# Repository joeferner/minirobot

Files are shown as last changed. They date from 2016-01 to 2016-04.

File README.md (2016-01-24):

# Minirobot

# Microcontroller Pin Requirements

| Name | Requirements | Pin |
| --- | --- | --- |
| Debug | UART TX/RX | UART1-PA9/PA10 |
| Wheel encoder left | EXTI | PB0 |
| Wheel encoder right | EXTI | PB1 |
| Wheel servo left | PWM | TIM3-PA6 |
| Wheel servo right | PWM | TIM3-PA7 |
| Line follow left outer  | EXTI | PB12 |
| Line follow right outer | EXTI | PB14 |
| Line follow left inner  | EXTI | PB13 |
| Line follow right inner | EXTI | PB15 |
| I<sup>2</sup>C1 | SCL/SDA | PB8/PB9 |
| Compass (ST-LIS3MDL) | I<sup>2</sup>C (0x1E) | I<sup>2</sup>C1 |
| Color Sensor (TCS3472)  | I<sup>2</sup>C (0x29) | I<sup>2</sup>C1 |
| Color Sensor Interrupt  | GPIO IN | PB6 |
| Color LED | PWM | TIM4-PB7 |
| Bluetooth (RN4020) | USART TX/RX/CTS/RTS | UART2-PA2/PA3/PA0/PA1 |
| Bluetooth MLDP | GPIO OUT | PC1 |
| Bluetooth WakeSW | GPIO OUT | PC2 |
| Bluetooth WakeHW | GPIO OUT | PC3 |
| Bluetooth WS | GPIO IN | PA4 |
| Bluetooth Connection | GPIO IN | PA5 |
| Bluetooth MLDPEV | GPIO IN | PC4 |
| Battery level | ADC | VBAT |

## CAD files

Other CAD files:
mechanical/BK-5003-ND.ipt
mechanical/LW-Q38E-Q100-3K6L-1.ipt
mechanical/QRE1113.ipt
mechanical/QRE1113GR.ipt
mechanical/SS-5GL-F.ipt
mechanical/TCS3472.ipt
mechanical/assembly-pcb.iam
mechanical/assembly.iam
mechanical/battery-aaa.ipt
mechanical/bottom-test.ipt
mechanical/micro-servo.ipt
mechanical/pcb.ipt
mechanical/wheel.ipt

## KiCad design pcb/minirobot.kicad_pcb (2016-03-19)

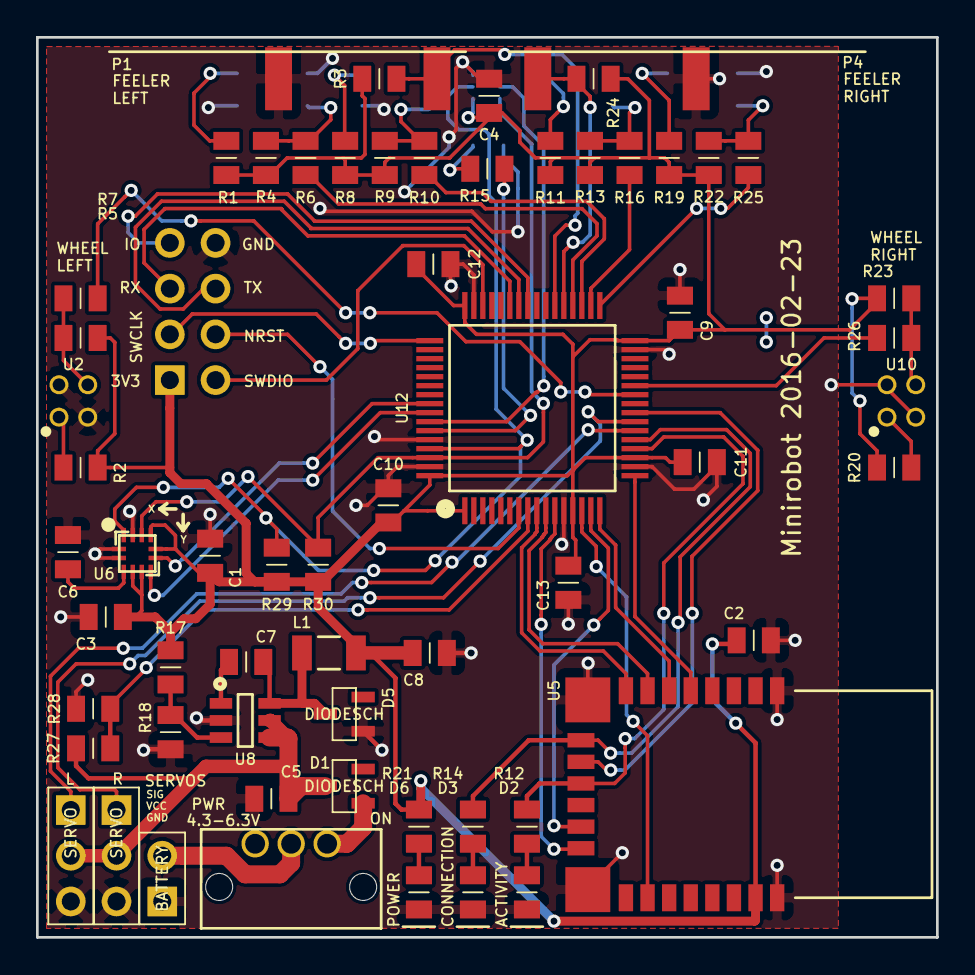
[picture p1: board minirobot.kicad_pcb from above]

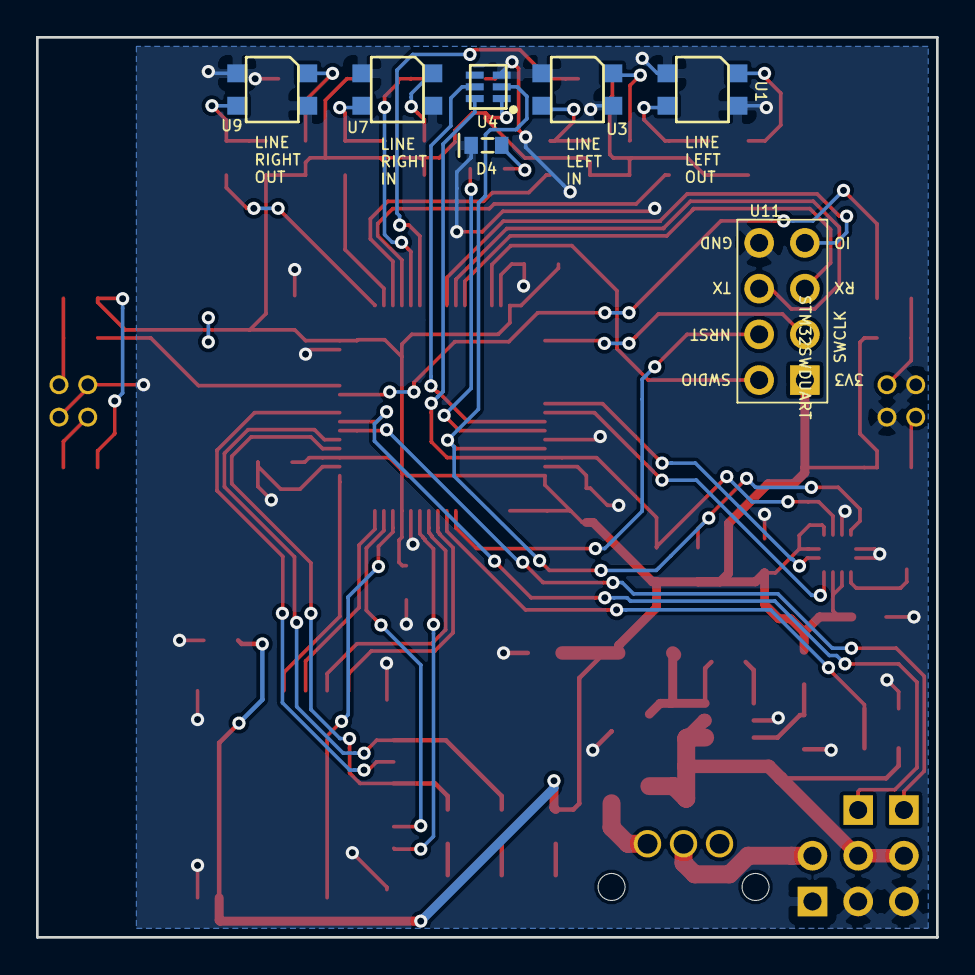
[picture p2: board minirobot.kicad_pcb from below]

Board: 2 copper layers, 50.0 x 50.0 mm, 68 parts (7 on the bottom side), 58 nets.

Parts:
C1, C4, C6, C9, C10, C11, C12, C13: 0.1uF; CAPC2012X100N
C2, C8: 10uF; CAPC2012X100N
C3: 1uF; CAPC2012X100N
C5: 10uF >6V; CAPC2012X100N
C7: 0.012uF; CAPC2012X100N
D1, D5: DIODESCH; SOT95P237X112_132-3N
D2: ACTIVITY-BLUE; LEDC2012X100N
D3: CONN-GREEN; LEDC2012X100N
D4: LED; LEDC1608X40N
D6: 3V3LED; LEDC2012X100N
L1: 4.7uH; INDC3218X180N
P1: FEELERLEFT; OMRON-SS-5GL-F-3-RAM
P2, P5: SERVO; HDRV3W66P254_1X3_762X249X838P
P3: BATTERY; HDRV2W66P254_1X2_508X249X838P
P4: FEELERRIGHT; OMRON-SS-5GL-F-3-RA
R1, R2, R8, R11, R15, R19, R20: 51R; RESC2012X100N
R3, R4, R5, R9, R13, R22, R23, R24, R27, R28: 10K; RESC2012X100N
R6, R7, R10, R16, R25, R26: 0R; RESC2012X100N
R12, R14, R21: 100R; RESC2012X100N
R17: 62K; RESC2012X100N
R18: 20K; RESC2012X100N
R29, R30: 4.7K; RESC2012X100N
S1: POWER; COPAL-MFS101D-6-Z
U1: LINELEFTOUT; QRE1113GR
U2: WHEELLEFT; QRE1113-RA
U3: LINELEFTIN; QRE1113GR
U4: TCS3472
U5: RN4020
U6: ST-LIS3MDL; LGA12S50P4X4_192X192X100
U7: LINERIGHTIN; QRE1113GR
U8: DIODES-AP3211; SOT95P270X145-6N
U9: LINERIGHTOUT; QRE1113GR
U10: WHEELRIGHT; QRE1113-RA
U11: STM32SWDUART; HDRV8W64P254_2X4_1016X483X838P
U12: STM32F411RET6; QFP50P1200X1200X160-64N

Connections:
+3.3V: C1.1, C2.1, C3.1, C4.1, C8.1, C9.1, C10.1, C11.1, C12.1, C13.1, L1.1, R1.1, R2.1, R3.2, R4.2, R5.2, R8.1, R9.2, R11.1, R13.2, R17.1, R19.1, R20.1, R21.1, R22.2, R23.2, R24.2, R29.1, R30.1, U4.1, U5.23, U6.5, U6.6, U6.9, U6.10, U11.1, U12.1, U12.13, U12.19, U12.32, U12.48, U12.64
/Bluetooth/BLECONN: R14.1, U5.10, U12.21
/Bluetooth/BLEMLDP: U5.8, U12.9
/Bluetooth/BLEMLDPEV: U5.11, U12.24
/Bluetooth/BLEUARTCTS: U5.14, U12.15
/Bluetooth/BLEUARTRTS: U5.18, U12.14
/Bluetooth/BLEUARTRX: U5.6, U12.16
/Bluetooth/BLEUARTTX: U5.5, U12.17
/Bluetooth/BLEWAKEHW: U5.15, U12.11
/Bluetooth/BLEWAKESW: U5.7, U12.10
/Bluetooth/BLEWS: R12.1, U5.12, U12.20
/Compass/COMPASSINT: U6.7, U12.57
/Compass/COMPASSRDY: U6.8, U12.56
/Compass/I2CSCL: R29.2, U4.2, U6.1, U12.61
/Compass/I2CSDA: R30.2, U4.6, U6.11, U12.62
/DEBUGGPIO: U11.7, U12.41
/DEBUGRX: U11.5, U12.43
/DEBUGTX: U11.6, U12.42
/NRST: U11.4, U12.7
/SWCLK: U11.3, U12.49
/SWDIO: U11.2, U12.46
/Sensors/COLORINT: U4.5, U12.58
/Sensors/COLORLED: R15.2, U12.59
/Sensors/FEELERLEFT: P1.1, R3.1, U12.38
/Sensors/FEELERRIGHT: P4.1, R24.1, U12.37
/Sensors/LINELEFTIN: R10.1, U12.35
/Sensors/LINELEFTOUT: R6.1, U12.36
/Sensors/LINERIGHTIN: R16.1, U12.34
/Sensors/LINERIGHTOUT: R25.1, U12.33
/Sensors/SERVOLEFT: P2.1, U12.22
/Sensors/SERVORIGHT: P5.1, U12.23
/Sensors/WHEELLEFT: R7.1, U12.26
/Sensors/WHEELRIGHT: R26.1, U12.27
/VBAT: R27.2, R28.1, U12.8
GNDPWR: C1.2, C2.2, C3.2, C4.2, C5.2, C6.2, C8.2, C9.2, C10.2, C11.2, C12.2, C13.2, D2.2, D3.2, D4.2, D5.1, D6.2, P1.2, P2.3, P3.1, P4.2, P5.3, R18.2, R28.2, U1.2, U1.4, U2.2, U2.4, U3.2, U3.4, U4.3, U5.1, U5.9, U5.16, U5.24, U6.2, U6.3, U6.12, U7.2, U7.4, U8.2, U9.2, U9.4, U10.2, U10.4, U11.8, U12.12, U12.18, U12.31, U12.47, U12.60, U12.63
unnamed: C6.1, U6.4
unnamed: C7.1, U8.1
unnamed: C7.2, D5.2, L1.2, U8.6
unnamed: D1.1, S1.3
unnamed: D2.1, R12.2
unnamed: D3.1, R14.2
unnamed: D4.1, R15.1
unnamed: D6.1, R21.2
unnamed: P3.2, S1.2
unnamed: R1.2, U1.1
unnamed: R2.2, U2.1
unnamed: R4.1, R6.2, U1.3
unnamed: R5.1, R7.2, U2.3
unnamed: R8.2, U3.1
unnamed: R9.1, R10.2, U3.3
unnamed: R11.2, U7.1
unnamed: R13.1, R16.2, U7.3
unnamed: R17.2, R18.1, U8.3
unnamed: R19.2, U9.1
unnamed: R20.2, U10.1
unnamed: R22.1, R25.2, U9.3
unnamed: R23.1, R26.2, U10.3
Vcc: C5.1, D1.2, P2.2, P5.2, R27.1, U8.4, U8.5

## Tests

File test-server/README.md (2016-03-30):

```
sudo modprobe btusb
sudo systemctl start bluetooth.service
sudo hciconfig hci0 up
sudo setcap cap_net_raw+eip $(eval readlink -f `which node`)
```

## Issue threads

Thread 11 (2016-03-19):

Move compass to make it easier to rework solder

joeferner, 2016-03-19:

Closed 2016-03-19.

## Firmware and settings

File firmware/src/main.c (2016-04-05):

#include "platform_config.h"
#include "compass.h"
#include "servo.h"
#include "colorSensor.h"
#include "exti.h"
#include "ble.h"
#include "battery.h"
#include <utils/debug.h>
#include <utils/time.h>
#include <utils/utils.h>
#include <string.h>

typedef enum {
  DEBUG_MODE_NOT_SET,
  DEBUG_MODE_SERVO,
  DEBUG_MODE_BLE
} _DebugMode;

void _printPrompt();

_DebugMode _debugMode;

void setup() {
  _debugMode = DEBUG_MODE_NOT_SET;
  debug_setup();
  sleep_ms(100);
  DEBUG_OUT("setup\n");

  assertNonOKHALStatus(compass_setup());
  assertNonOKHALStatus(servo_setup());
  assertNonOKHALStatus(exti_setup());
  assertNonOKHALStatus(colorSensor_setup());
  assertNonOKHALStatus(ble_setup());
  assertNonOKHALStatus(battery_setup());

  colorSensor_setGain(1);
  ble_updateColorSensorGain(1);

  colorSensor_setLedBrightness(50);
  ble_updateColorSensorLedBrightness(50);

  DEBUG_OUT("setup complete\n");
  _printPrompt();
}

void loop() {
  debug_tick();
  compass_tick();
  servo_tick();
  colorSensor_tick();
  ble_tick();
  battery_tick();
}

void onBatteryLevelUpdate(uint8_t level) {
  //DEBUG_OUT("battery level: %d\n", level);
  ble_updateBatteryLevel(level);
}

void onFeeler(Feeler feeler, bool active) {
  /*
  DEBUG_OUT(
    "feeler: %s %s\n",
    feeler == FEELER_LEFT ? "left" : "right",
    active ? "on" : "off"
  );
  */
  ble_updateFeeler(feeler, active);
}

void onWheelSensor(WheelSensor wheelSensor, bool active) {
  /*
  DEBUG_OUT(
    "wheelSensor: %s %s\n",
    wheelSensor == WHEEL_SENSOR_LEFT ? "left" : "right",
    active ? "on" : "off"
  );
  */
}

void onLineSensor(LineSensor lineSensor, bool active) {
  /*
  const char* sensorName = "";
  switch (lineSensor) {
  case LINE_SENSOR_LEFT_IN:
    sensorName = "left in";
    break;
  case LINE_SENSOR_LEFT_OUT:
    sensorName = "left out";
    break;
  case LINE_SENSOR_RIGHT_IN:
    sensorName = "right in";
    break;
  case LINE_SENSOR_RIGHT_OUT:
    sensorName = "right out";
    break;
  }
  DEBUG_OUT("lineSensor: %s %s\n", sensorName, active ? "on" : "off");
  */
  ble_updateLineSensor(lineSensor, active);
}

void onBLESetMotor(int8_t left, int8_t right) {
  DEBUG_OUT("ble set motor: %d %d\n", left, right);
  servo_setSpeed(left, right);
}

void onBLEWriteConfiguration(BLE_Configuration* configuration) {
  colorSensor_setGain(configuration->colorSensorGain);
  colorSensor_setLedBrightness(configuration->colorSensorLedBrightness);
}

void onCompassChange(uint16_t heading) {
  //DEBUG_OUT("heading: %d\n", heading);
  ble_updateCompass(heading);
}

void onColorSensorData(ColorSensorData* colorData) {
  //DEBUG_OUT("colorSensor: r,g,b,c=>%d,%d,%d,%d\n", colorData->r, colorData->g, colorData->b, colorData->c);
  ble_updateColorSensorData(colorData);
}

void debug_processLine(const char* line) {
  if (strlen(line) == 0) {
  } else if (strcmp(line, "exit") == 0) {
    _debugMode = DEBUG_MODE_NOT_SET;
  } else if (strcmp(line, "servo") == 0) {
    _debugMode = DEBUG_MODE_SERVO;
  } else if (strcmp(line, "ble") == 0) {
    _debugMode = DEBUG_MODE_BLE;
  } else {
    bool result = false;
    switch (_debugMode) {
    case DEBUG_MODE_NOT_SET:
      break;
    case DEBUG_MODE_SERVO:
      result = servo_debugProcessLine(line);
      break;
    case DEBUG_MODE_BLE:
      result = ble_debugProcessLine(line);
      break;
    default:
      printf("unhandled debug mode %d\n", _debugMode);
      result = true;
      break;
    }
    if (!result) {
      printf("invalid debug command: %s\n", line);
    }
  }
  _printPrompt();
}

void _printPrompt() {
  switch (_debugMode) {
  case DEBUG_MODE_NOT_SET:
    break;
  case DEBUG_MODE_SERVO:
    printf("servo");
    break;
  case DEBUG_MODE_BLE:
    printf("ble");
    break;
  default:
    printf("unknown");
    break;
  }
  printf("> ");
}

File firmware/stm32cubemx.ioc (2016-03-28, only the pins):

Mcu.UserName=STM32F411RETx
PA0-WKUP.Signal=USART2_CTS
PA1.Signal=USART2_RTS
PA10.Signal=USART1_RX
PA13.Signal=SYS_JTMS-SWDIO
PA14.Signal=SYS_JTCK-SWCLK
PA2.Signal=USART2_TX
PA3.Signal=USART2_RX
PA4.GPIO_Label=BLE_WS
PA4.Signal=GPIO_Input
PA5.GPIO_Label=BLE_CONN
PA5.Signal=GPIO_Input
PA6.GPIO_Label=SERVO_LEFT
PA6.Signal=S_TIM3_CH1
PA7.GPIO_Label=SERVO_RIGHT
PA7.Signal=S_TIM3_CH2
PA8.GPIO_Label=DEBUG_GPIO
PA8.Signal=GPIO_Output
PA9.Signal=USART1_TX
PB0.GPIO_Label=WHEEL_LEFT
PB0.Signal=GPXTI0
PB1.GPIO_Label=WHEEL_RIGHT
PB1.Signal=GPXTI1
PB12.GPIO_Label=LINE_RIGHT_OUT
PB12.Signal=GPXTI12
PB13.GPIO_Label=LINE_RIGHT_IN
PB13.Signal=GPXTI13
PB14.GPIO_Label=LINE_LEFT_IN
PB14.Signal=GPXTI14
PB15.GPIO_Label=LINE_LEFT_OUT
PB15.Signal=GPXTI15
PB4.GPIO_Label=COMPASS_RDY
PB4.Signal=GPXTI4
PB5.GPIO_Label=COMPASS_INT
PB5.Signal=GPXTI5
PB6.GPIO_Label=COLOR_INT
PB6.Signal=GPIO_Input
PB7.GPIO_Label=COLOR_LED
PB7.Signal=S_TIM4_CH2
PB8.Signal=I2C1_SCL
PB9.Signal=I2C1_SDA
PC0.GPIO_Label=VBAT
PC0.Signal=ADCx_IN10
PC1.GPIO_Label=BLE_MLDP
PC1.Signal=GPIO_Output
PC2.GPIO_Label=BLE_WAKESW
PC2.Signal=GPIO_Output
PC3.GPIO_Label=BLE_WAKEHW
PC3.Signal=GPIO_Output
PC4.GPIO_Label=BLE_MLDPEV
PC4.Signal=GPIO_Input
PC6.GPIO_Label=FEELER_RIGHT
PC6.Signal=GPXTI6
PC7.GPIO_Label=FEELER_LEFT
PC7.Signal=GPXTI7

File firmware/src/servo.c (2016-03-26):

#include "servo.h"
#include <stdlib.h>
#include <string.h>
#include <utils/utils.h>

#define _SERVO_PERIOD() ((int32_t)SERVO_TIMER.Init.Period)

TIM_HandleTypeDef _servo_timHandle;

HAL_StatusTypeDef _servo_setPulse(uint32_t channel, uint32_t pulse);
HAL_StatusTypeDef _servo_setSpeed(uint32_t channel, int16_t speed);
uint32_t _servo_calculatePulse(int16_t speed);

HAL_StatusTypeDef servo_setup() {
  DEBUG_OUT("servo setup\n");

  returnNonOKHALStatus(servo_allStop());
  returnNonOKHALStatus(HAL_TIM_PWM_Start(&SERVO_TIMER, SERVO_LEFT_CH));
  returnNonOKHALStatus(HAL_TIM_PWM_Start(&SERVO_TIMER, SERVO_RIGHT_CH));

  return HAL_OK;
}

HAL_StatusTypeDef servo_tick() {
  return HAL_OK;
}

HAL_StatusTypeDef servo_allStop() {
  return servo_setSpeed(0, 0);
}

HAL_StatusTypeDef servo_setSpeed(int16_t leftSpeed, int16_t rightSpeed) {
  HAL_StatusTypeDef resultLeft = _servo_setSpeed(SERVO_LEFT_CH, leftSpeed);
  HAL_StatusTypeDef resultRight = _servo_setSpeed(SERVO_RIGHT_CH, rightSpeed);
  if (resultLeft != HAL_OK) {
    return resultLeft;
  }
  if (resultRight != HAL_OK) {
    return resultRight;
  }
  return HAL_OK;
}

HAL_StatusTypeDef servo_setLeftSpeed(int16_t leftSpeed) {
  return _servo_setSpeed(SERVO_LEFT_CH, leftSpeed);
}

HAL_StatusTypeDef servo_setRightSpeed(int16_t rightSpeed) {
  return _servo_setSpeed(SERVO_RIGHT_CH, rightSpeed);
}

HAL_StatusTypeDef _servo_setSpeed(uint32_t channel, int16_t speed) {
  uint32_t pulse = _servo_calculatePulse(speed);
  return _servo_setPulse(channel, pulse);
}

uint32_t _servo_calculatePulse(int16_t speed) {
  if (speed == 0) {
    return 0;
  }
  int32_t clampedSpeed = clamp(speed, -100, 100);

  // PPM - assuming the period is set to 20ms we need to generate a pulse between
  // 0.5ms/2.5% (full reverse) and 2.5ms/12.5% (full forward) with stop being the
  // midpoint 1.5ms/7.5%
  int32_t totalPeriod = _SERVO_PERIOD();
  int32_t workingPeriod = (totalPeriod * (125 - 25)) / 10 / 100; // = totalPeriod * (12.5% - 2.5%) = totalPeriod * (12.5 - 2.5)/100
  int32_t zeroOffset = (totalPeriod * 25) / 10 / 100; // = totalPeriod * 2.5% = totalPeriod * 2.5/100
  int32_t speedPercent = (clampedSpeed + 100) / 2;
  int32_t pulse = zeroOffset + (workingPeriod * speedPercent / 100);
  return pulse;
}

HAL_StatusTypeDef _servo_setPulse(uint32_t channel, uint32_t pulse) {
  __HAL_TIM_SET_COMPARE(&SERVO_TIMER, channel, pulse);
  return HAL_OK;
}

bool servo_debugProcessLine(const char* line) {
  HAL_StatusTypeDef result;
  char* ch;
  if (line[0] == 'l' || line[1] == 'L') {
    int16_t newLeftSpeed = atoi(line + 1);
    result = servo_setLeftSpeed(newLeftSpeed);
    if (result == HAL_OK) {
      printf("OK left %d\n", newLeftSpeed);
    } else {
      printf("FAIL %d\n", result);
    }
    return true;
  } else if (line[0] == 'r' || line[1] == 'R') {
    int16_t newRightSpeed = atoi(line + 1);
    result = servo_setRightSpeed(newRightSpeed);
    if (result == HAL_OK) {
      printf("OK right %d\n", newRightSpeed);
    } else {
      printf("FAIL %d\n", result);
    }
    return true;
  } else if ((ch = strchr(line, ',')) != NULL) {
    char leftStr[100];
    strncpy(leftStr, line, ch - line);
    int16_t leftSpeed = atoi(leftStr);
    int16_t rightSpeed = atoi(ch + 1);
    result = servo_setSpeed(leftSpeed, rightSpeed);
    if (result == HAL_OK) {
      printf("OK %d, %d\n", leftSpeed, rightSpeed);
    } else {
      printf("FAIL %d\n", result);
    }
    return true;
  } else if (strcmp(line, "stop") == 0) {
    result = servo_allStop();
    if (result == HAL_OK) {
      printf("OK all stop\n");
    } else {
      printf("FAIL %d\n", result);
    }
    return true;
  }
  return false;
}

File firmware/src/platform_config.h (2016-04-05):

#ifndef _PLATFORM_CONFIG_H_
#define _PLATFORM_CONFIG_H_

#include <pinout.h>

#define DEBUG

#ifdef DEBUG
#  define UTILS_DEBUG /* print assert statements */
#endif
#define DEBUG_UART       huart1
#define MAX_TIMEOUT      0xffff

//#define LIS3MDL_DEBUG
#define COMPASS_I2C      hi2c1
#define COMPASS_TIMER_MS 20

#define SERVO_TIMER      htim3
#define SERVO_LEFT_CH    TIM_CHANNEL_1
#define SERVO_RIGHT_CH   TIM_CHANNEL_2

//#define TCS3472_DEBUG
#define COLOR_SENSOR_CHANGE_THRESHOLD 10
#define COLOR_SENSOR_I2C              hi2c1
#define COLOR_SENSOR_LED_TIMER        htim4
#define COLOR_SENSOR_LED_TIMER_CH     TIM_CHANNEL_2
#define TCS3472_INTEGRATION_TIME      0xd5 /* 101ms */
#define TCS3472_INTEGRATION_TIMEMS    101

//#define RN4020_DEBUG
#define BLE_UART              huart2
#define BLE_DEVICE_NAME       "bot" /* max 6 - 4 (4 digits of MAC) */
#define BLE_MANUFACTURER_NAME "joeferner"
#define BLE_MODEL_NUMBER      "1.0"
#define BLE_SERIAL_NUMBER     "000001"
#define BLE_HARDWARE_REVISION "2016-02-23"
#define BLE_SOFTWARE_REVISION "1.0"
#define BLE_SYSTEM_ID         BLE_DEVICE_NAME

#define BATTERY_UPDATE_INTERVAL_MS 5000
#define BATTERY_MAX_VALUE          100
#define BATTERY_ADC                hadc1

#ifdef DEBUG
#  define DEBUG_OUT(format, ...) printf("%s:%d: " format, __FILE__, __LINE__, ##__VA_ARGS__)
#else
#  define DEBUG_OUT(format, ...)
#endif

extern UART_HandleTypeDef huart1;
extern UART_HandleTypeDef huart2;
extern I2C_HandleTypeDef hi2c1;
extern TIM_HandleTypeDef htim3;
extern TIM_HandleTypeDef htim4;
extern ADC_HandleTypeDef hadc1;

#endif

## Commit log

2016-01-12 initial mechanical
    [assembly.iam, battery-aaa.ipt, micro-servo.ipt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]
2016-01-21 initial schematic
    [minirobot.kicad_pcb, minirobot.sch]
2016-01-21 add compass
    [minirobot.sch]
2016-01-22 battery level
    [minirobot.sch]
2016-01-25 update schematics
    [minirobot-bluetooth.sch, minirobot-compass.sch, minirobot-power.sch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]
2016-01-25 assign inventory ids
    [minirobot-bluetooth.sch, minirobot-compass.sch, minirobot-power.sch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]
2016-01-26 more schematics
    [minirobot-bluetooth.sch, minirobot-power.sch, minirobot-sensors.sch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]
2016-01-30 initial part layout
    [BK-5003-ND.ipt, LW-Q38E-Q100-3K6L-1.ipt, QRE1113.ipt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]
2016-02-11 pcb routing complete
    [minirobot.kicad_pcb, minirobot.sch]
2016-02-22 finish layout
    [minirobot.kicad_pcb]
2016-02-29 2016-02-23 pcb
    [minirobot.drl, minirobot.gbl, minirobot.gbo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]
2016-03-19 debug uart working
2016-03-19 extend compass leads to help with rework
    [minirobot.kicad_pcb]
2016-03-19 add compass x/y markings on silk
    [minirobot.kicad_pcb]
2016-03-19 move SWD/Debug connector to make it easier for compass rework
    [minirobot.kicad_pcb]
2016-03-26 working servo
2016-03-26 working line and wheel sensors
    [minirobot-sensors.sch]
2016-03-27 working color sensor
2016-03-28 working BLE and battery level
2016-03-30 working BLE connect and battery level
2016-03-31 support real time read of battery:
2016-04-01 get/set motor
2016-04-02 write motor speed
2016-04-05 bottom test mech
    [SS-5GL-F.ipt, assembly-pcb.iam, bottom-test.ipt]
